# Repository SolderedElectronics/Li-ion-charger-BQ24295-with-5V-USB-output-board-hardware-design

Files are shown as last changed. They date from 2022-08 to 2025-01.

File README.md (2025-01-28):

# Li-ion charger BQ24295 with 5V USB output board Hardware Design

## About the Product

| Li-ion charger BQ24295 with 5V USB output board Image |
| :----------------------------------------------------------: |
| [Buy Li-ion charger BQ24295 with 5V USB output board](https://www.solde.red/333075) |

The BQ24295 is a versatile Li-ion battery charger designed to provide efficient and reliable charging for single-cell lithium-ion or lithium-polymer batteries. It supports various charging modes, including constant current (CC) and constant voltage (CV) charging, to ensure the battery is charged quickly and safely.

The BQ24295 charger operates on a wide input voltage range, typically from 4.35V to 17V, allowing it to be powered by a variety of power sources, including USB ports and AC adapters. It also features integrated power path management, which allows simultaneous charging of the battery while powering the connected device, providing uninterrupted operation.

---

## Repository Contents

This repository contains all design files for Li-ion charger BQ24295 with 5V USB output board, organized as follows:

- **`CAD` folder**: Contains KiCAD design files, including:
  - Schematics
  - PCB layout
  - Panel PCB layout
  - Source 3D files in Fusion360, if any
  - All files are sorted by version with a detailed change log.
- **`OUTPUTS` folder**: Includes all production-ready files, such as:
  - Bill of Materials (BOM) and interactive BOM (iBOM)
  - PDF versions of schematics
  - 3D `.step` file of the board
  - 3D-printable models
  - Gerber files for PCB manufacturing
  - Image of the pinout of the board
  - Product image
  - Compliance, legal and generic sales documents

Refer to the `Change Log` in the CAD folder for details about updates between versions.

---

## Learn More About the Product

Beyond the repository, explore the following resources:

### Soldered Verify

Soldered Verify Logo

The **Soldered Verify** system ensures every board you purchase from Soldered is fully functional. It also provides access to exclusive test data for your product. To get started, find the unique Soldered Verify ID on your product's packaging and enter the ID on the [Soldered Verify page](https://soldered.com/verify/) to access test results and additional product details.

### Soldered Community

soldered-verify-logo

Soldered Community is your go-to place for technical support. Our engineers track and answer all questions posted there, and it’s a great space for the maker community. Get answers to your questions and solutions for your challenges at [Soldered Community](https://soldered.com/community).

### solde.red

solde.red is an ultimate URL shortener and information hub. Access it by typing solde.red/ followed by your product SKU, e.g., [solde.red/333000](https://solde.red/333000), to find getting-started guides, datasheets, open-source hardware and software files, certifications, images, pinouts, and more. Read more about the shortener [here](https://solde.red/info/).

---

## Contributing

Contributions are welcome! Here’s how you can get involved:

- Submit pull requests to enhance the design or fix issues.
- Report bugs or problems by opening an issue.

We encourage community collaboration to make this product even better.

---

## About Soldered

soldered-logo

[Soldered for Makers](https://soldered.com) specializes in designing and manufacturing electronic products tailored for enthusiasts, ranging from hobbyists to professionals. Our portfolio includes electronic boards, sensors, and actuators that are widely utilized in fields such as microelectronics, mechatronics, robotics, programming, and IoT. Every product we offer is designed in-house and built upon open-source hardware and software platforms. Proudly certified and manufactured within the European Union, our catalog likely includes the product you need for your project.

We complement these products with comprehensive tutorials and manuals, product descriptions, schematics, programming codes, and project examples. Our round-the-clock [customer and technical support](https://soldered.com/community) is available for all our products, irrespective of the sales channel. Soldered’s success and services reflect our maker community’s unwavering [trust](https://www.trustpilot.com/review/soldered.com), for which we are deeply grateful. Join our community and create using Soldered products.

---

## License

All Soldered open-source hardware (OSH) is under The TAPR Open Hardware License. Read more in the LICENSE file located in this repository.

**Disclaimer:**

No warranty - all designs in this repository are distributed in the hope that they will be useful, but without any warranty. They are provided "AS IS", therefore without warranty of any kind, either expressed or implied. The entire quality and performance of what you do with the contents of this repository are your responsibility. In no event Soldered Electronics will be liable for your damages, or losses, including any general, special, incidental, or consequential damage arising out of the use or inability to use the contents of this repository. 

---

## Have fun!

Thank you for your support from your fellow makers at Soldered Electronics.

Happy Making!

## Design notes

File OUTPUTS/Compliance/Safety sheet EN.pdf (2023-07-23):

## Regulatory Compliance and Important Safety Information

PLEASE RETAIN THIS INFORMATION FOR FUTURE REFERENCE.

BEFORE USING THIS PRODUCT, READ ALL INSTRUCTION IN THIS DOCUMENT.

Product name: | Li-ion charger BQ24295 with 5V USB output board
Getting started: | To get started, please visit www.soldered.com

# WARNINGS

- This product should not be covered and should be operated in well ventilated enviroment.
- The product should be placed on a stable, flat, non-conductive surface and should not be contacted by conductive items.
- Connection of other devices may affect compliance or result in damage to the unit, and invalidate the warranty.
- Where peripherals are connected that do not include the cable or connector, the cable or connector used must offer adequate insulation and operation in order that the requirements of the relevant performance and safety requirements are met.
- There is a danger of explosion if the battery is incorrectly placed.
- The product should not be used outside of its specified working range.

# INSTRUCTIONS FOR SAFE USE

To avoid malfunction or damage to your device, please observe the following:
- Do not expose it to water, moisture or place on a conductive surface when turned on. Do not handle the unit with wet hands.
- Do not expose it to heat from any source; the product is designed to be used at normal ambient room temperatures. The product is intended to be used inside.
- Take care when handling to avoid mechanical or electrical damage to any part of the unit. Avoid handling the unit while it's powered. Use ESD protection.
- Use only supplied cable (or the cable of the same or higher quality) with the unit.

# COMPLIANCE INFORMATION

The product complies with the relevant provision of the RoHS Directive for the European Union. In common with all Electrical and Electronic Equipment (EEE), the product should not be disposed household waste.

ELECTROMAGNETIC COMPABILITY AND OPERATION

- The product is in conformity with the protection requirements of EU Council Directive 2014/30/EU on the laws of the Member States relating of electromagnetic compability, and Electromagnetic Compability Regulations 2016 of the UK.
- WARNING: Please do not alter the design of this product, doing so may void your ability to use the product freely, this includes altering the frequency at which product operates.

Soldered Electronics d.o.o., Reisnerova ulica 100, 31000 Osijek, Croatia. VAT ID: HR83200237288

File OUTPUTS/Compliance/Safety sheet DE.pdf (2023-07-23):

## Einhaltung gesetzlicher Vorschriften und wichtige Sicherheitsinformationen

BITTE BEWAHREN SIE DIESE INFORMATIONEN ZUR SPÄTEREN VERWENDUNG AUF.

LESEN SIE VOR DER VERWENDUNG DIESES PRODUKTS ALLE ANWEISUNGEN IN DOKUMENT.

Produktname: | Li-ion charger BQ24295 with 5V USB output board
Die ersten Schritte: | Besuchen Sie www.soldered.com, um loszulegen.

# WARNUNGEN

- Dieses Produkt sollte nicht abgedeckt werden und in einer gut belüfteten Umgebung betrieben werden.
- Das Produkt sollte auf einer stabilen, flachen, nicht leitenden Oberfläche aufgestellt werden und nicht mit leitenden Gegenständen in Berührung kommen.
- Der Anschluss anderer Geräte kann die Konformität beeinträchtigen oder zu Schäden am Gerät führen und zum Erlöschen der Garantie führen.
- Wenn Peripheriegeräte angeschlossen werden, die nicht das Kabel oder den Stecker enthalten, muss das verwendete Kabel oder muss das verwendete Kabel bzw. der verwendete Steckverbinder eine angemessene Isolierung und Funktion aufweisen, damit die Anforderungen die einschlägigen Leistungs- und Sicherheitsanforderungen erfüllt werden.
- Es besteht Explosionsgefahr, wenn die Batterie falsch eingesetzt wird.
- Das Produkt sollte nicht außerhalb des angegebenen Arbeitsbereichs verwendet werden.

# HINWEISE ZUR SICHEREN ANWENDUNG

Um Fehlfunktionen oder Schäden an Ihrem Gerät zu vermeiden, beachten Sie bitte die folgenden Hinweise:
- Setzen Sie das Gerät nicht Wasser oder Feuchtigkeit aus und stellen Sie es nicht auf eine
leitende Oberfläche, wenn es eingeschaltet ist. Das Gerät nicht mit nassen Händen anfassen.
- Setzen Sie es keiner Wärmequelle aus; das Produkt ist für die Verwendung bei normalen Raumtemperaturen ausgelegt. Das Produkt ist für die Verwendung in Innenräumen vorgesehen.
- Seien Sie bei der Handhabung vorsichtig, um mechanische oder elektrische Schäden an Teilen des Geräts zu vermeiden. Fassen Sie das Gerät nicht an, wenn es unter Spannung steht. Verwenden Sie einen ESD-Schutz.
- Verwenden Sie nur das mitgelieferte Kabel (oder ein gleich- oder höherwertiges Kabel)
mit dem Gerät.

# COMPLIANCE-INFORMATIONEN

Das Produkt entspricht den entsprechenden Bestimmungen der RoHS-Richtlinie für die Europäische Union. Wie alle elektrischen und elektronischen Geräte (EEE), sollte das Produkt nicht über den Hausmüll entsorgt werden.
ELEKTROMAGNETISCHE VERTRÄGLICHKEIT UND BETRIEB
- Das Produkt entspricht den Schutzanforderungen der Richtlinie des EU-Rates 2014/30/EU über die Rechtsvorschriften der Mitgliedstaaten zur elektromagnetischen Verträglichkeit und den Elektromagnetische Verträglichkeitsverordnung 2016 des Vereinigten Königreichs.
- WARNUNG: Bitte verändern Sie nicht das Design dieses Produkts, da dies dazu führen kann, dass Sie das Produkt nicht mehr uneingeschränkt nutzen können.
Dies gilt auch für die Änderung der Frequenz, mit der das Produkt arbeitet.

Soldered Electronics d.o.o., Reisnerova ulica 100, 31000 Osijek, Croatia. VAT ID: HR83200237288

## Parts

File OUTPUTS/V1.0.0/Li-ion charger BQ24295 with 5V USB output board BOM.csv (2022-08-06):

Id | Designator | Package | Quantity | Designation | Supplier and ref
1 | G*** | Symbol-Front-USB | 1 | LOGO
2 | U1 | SOT-363 | 1 | NMOS-DUAL
3 | C4 | 0603C | 1 | CL10B473KO8NNNC
4 | G*** | Logo-Back-OSH-3.5mm | 1 | LOGO
5 | R12,R14,R1 | 0603R | 3 | 5.1k
6 | R3,R6,R10,R9,R8,R5,R2,R7 | 0603R | 8 | 10k
7 | K12 | USB_A_FEMALE_CONECTOR | 1 | USB_A_FEMALE_CONNECTOR
8 | D2 | 0402LED | 1 | purple
9 | ,,,,,,,,,,,,,,,,,,,,,,,,, | buzzardLabel | 26
10 | K6 | HEADER_MALE_4X1 | 1 | HEADER_MALE_4X1
11 | K4 | U262-161N-4BVC11 | 1 | U262-161N-4BVC11
12 | R15 | 0603R | 1 | 1k
13 | JP3,JP1 | SMD_JUMPER_3_PAD_TRACE | 2 | SMD_JUMPER_3_PAD_TRACE
14 | U2 | BQ24295RGET | 1 | BQ24295_RGET
15 | JP6,JP2 | SMD-JUMPER-CONNECTED_TRACE_SLODERMASK | 2 | SMD-JUMPER-CONNECTED_TRACE_SLODERMASK
16 | D1 | 0402LED | 1 | red
17 | G***,G*** | Logo-Front-easyC-5mm | 2 | LOGO
18 | FD1 | FIDUCIAL_23 | 1 | FIDUCIAL
19 | JP5 | SMD_JUMPER | 1 | SMD_JUMPER
20 | C2 | 1206C | 1 | EMK316BB7226ML-T
21 | K1,K10 | HEADER_MALE_2X1 | 2 | HEADER_MALE_2X1
22 | K2,K3,K8,K9 | HEADER_MALE_1X1 | 4 | HEADER_MALE_1X1
23 | H1,H2,H4,H3 | HOLE_3.2mm | 4 | HOLE_3.2mm
24 | R11,R16 | 0402R | 2 | 2k2
25 | K7 | JST-2pin-SMD | 1 | JST-2pin-SMD
26 | K5,K11 | easyC-connector | 2 | easyC-SMD
27 | C7,C5,C6 | 1206C | 3 | CL31B106MOHNNNE
28 | L1 | SRN5020TA-2R2M | 1 | SRN5020TA__2R2M
29 | U3 | SOT-23-5 | 1 | SE5218
30 | REF** | Logo-Back-SolderedFULL-20mm | 1 | Logo-Front-SolderedFULL-20mm
31 | R13 | 0603R | 1 | 150R
32 | G*** | Symbol-Front-Battery | 1 | LOGO
33 | C3 | 0805C | 1 | GRM21BR71C475KE51K
34 | G*** | Logo-Front-Soldered-6mm | 1 | LOGO
35 | R4 | 0603R | 1 | 33k
36 | C8,C9 | 0603C | 2 | 2.2uF
37 | C1 | 0603C | 1 | CL10B105KO8NNNL
38 | JP4 | SMD_JUMPER_CONNECTED | 1 | SMD-JUMPER-CONNECTED
39 | Ref** | Version1.0.0. | 1 | Val**
40 | REF** | Symbol-Front-I2C-ADDR-Field | 1 | Symbol-Front-I2C-ADDR-Field

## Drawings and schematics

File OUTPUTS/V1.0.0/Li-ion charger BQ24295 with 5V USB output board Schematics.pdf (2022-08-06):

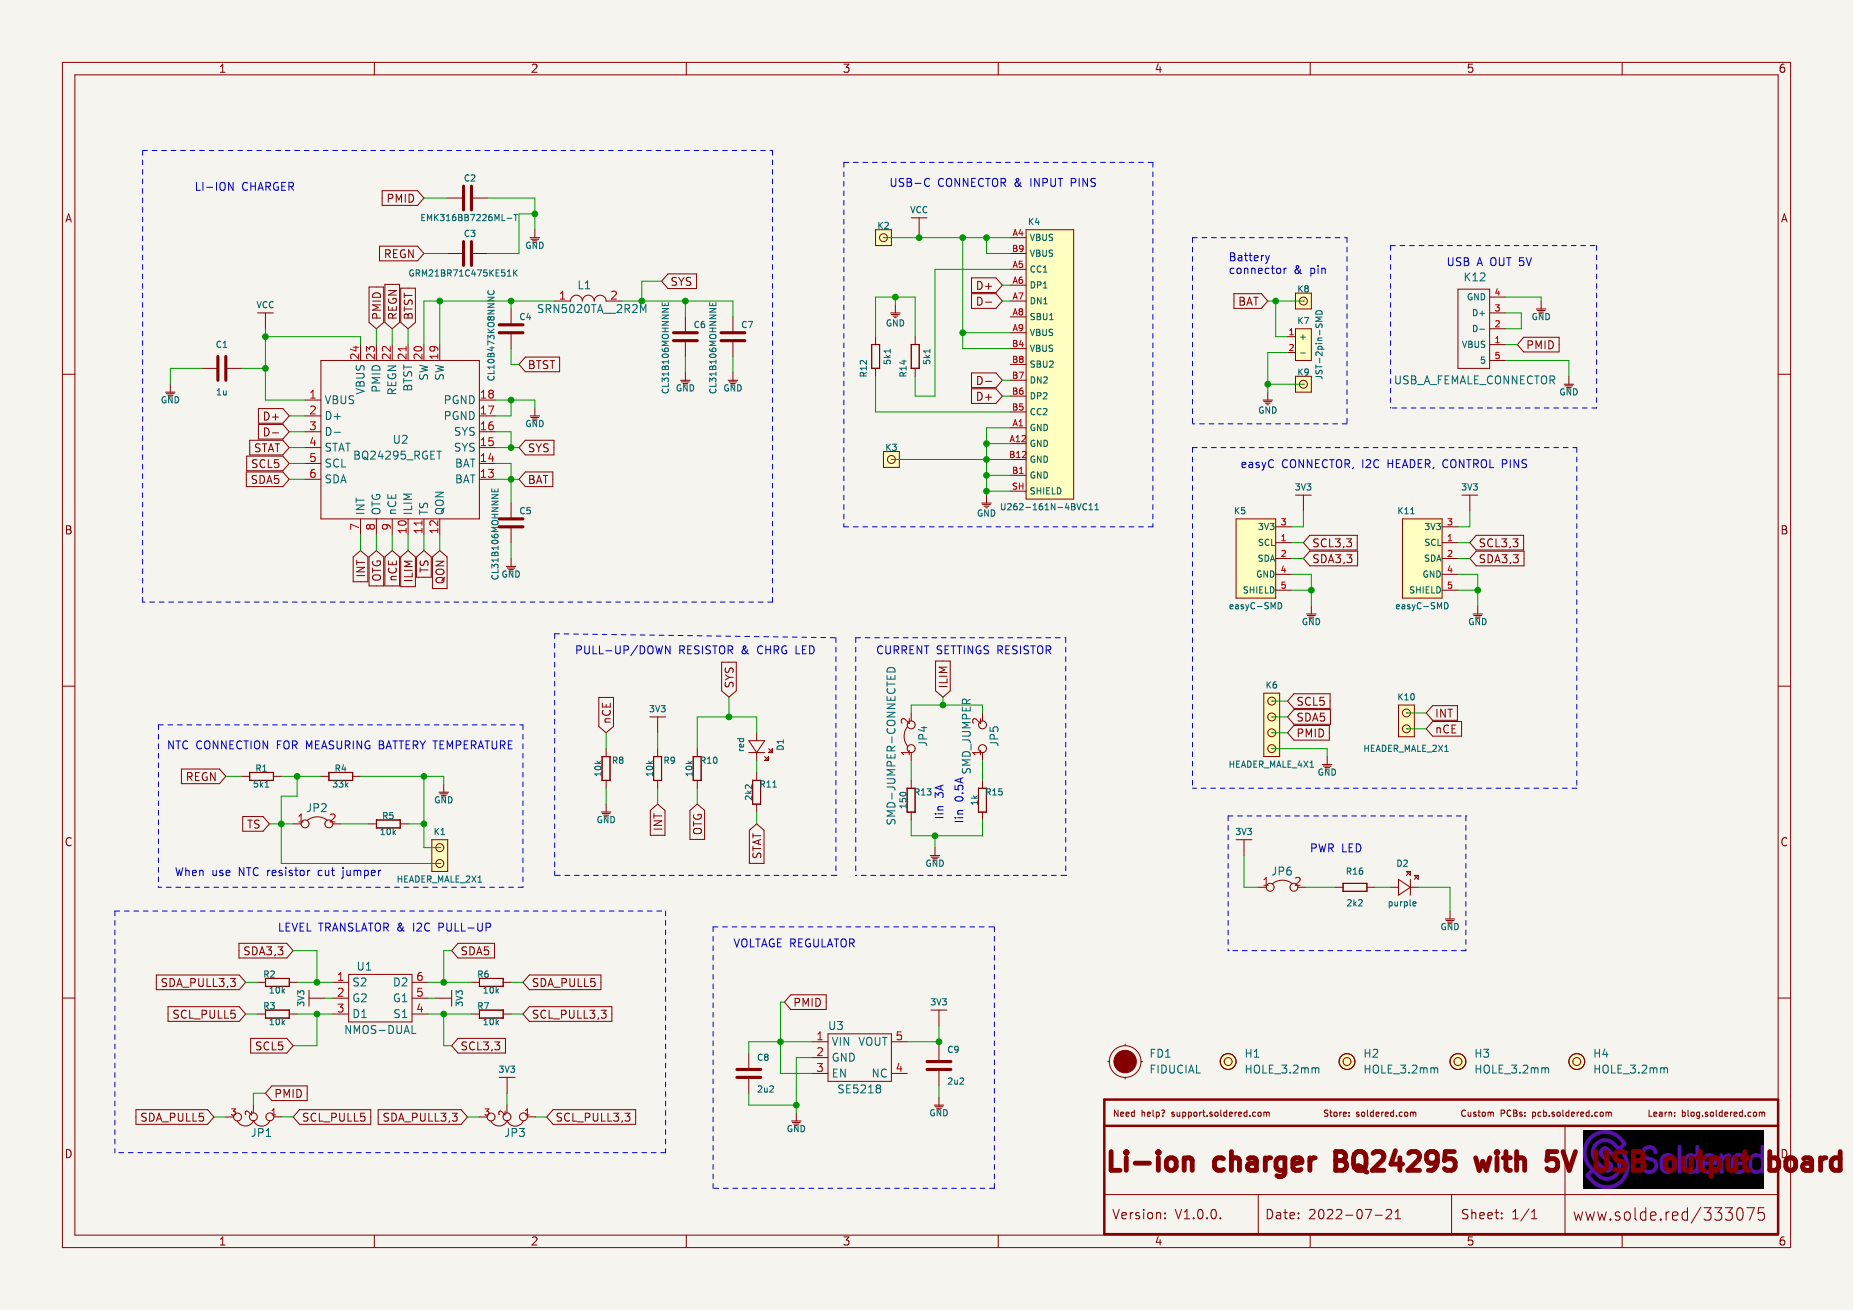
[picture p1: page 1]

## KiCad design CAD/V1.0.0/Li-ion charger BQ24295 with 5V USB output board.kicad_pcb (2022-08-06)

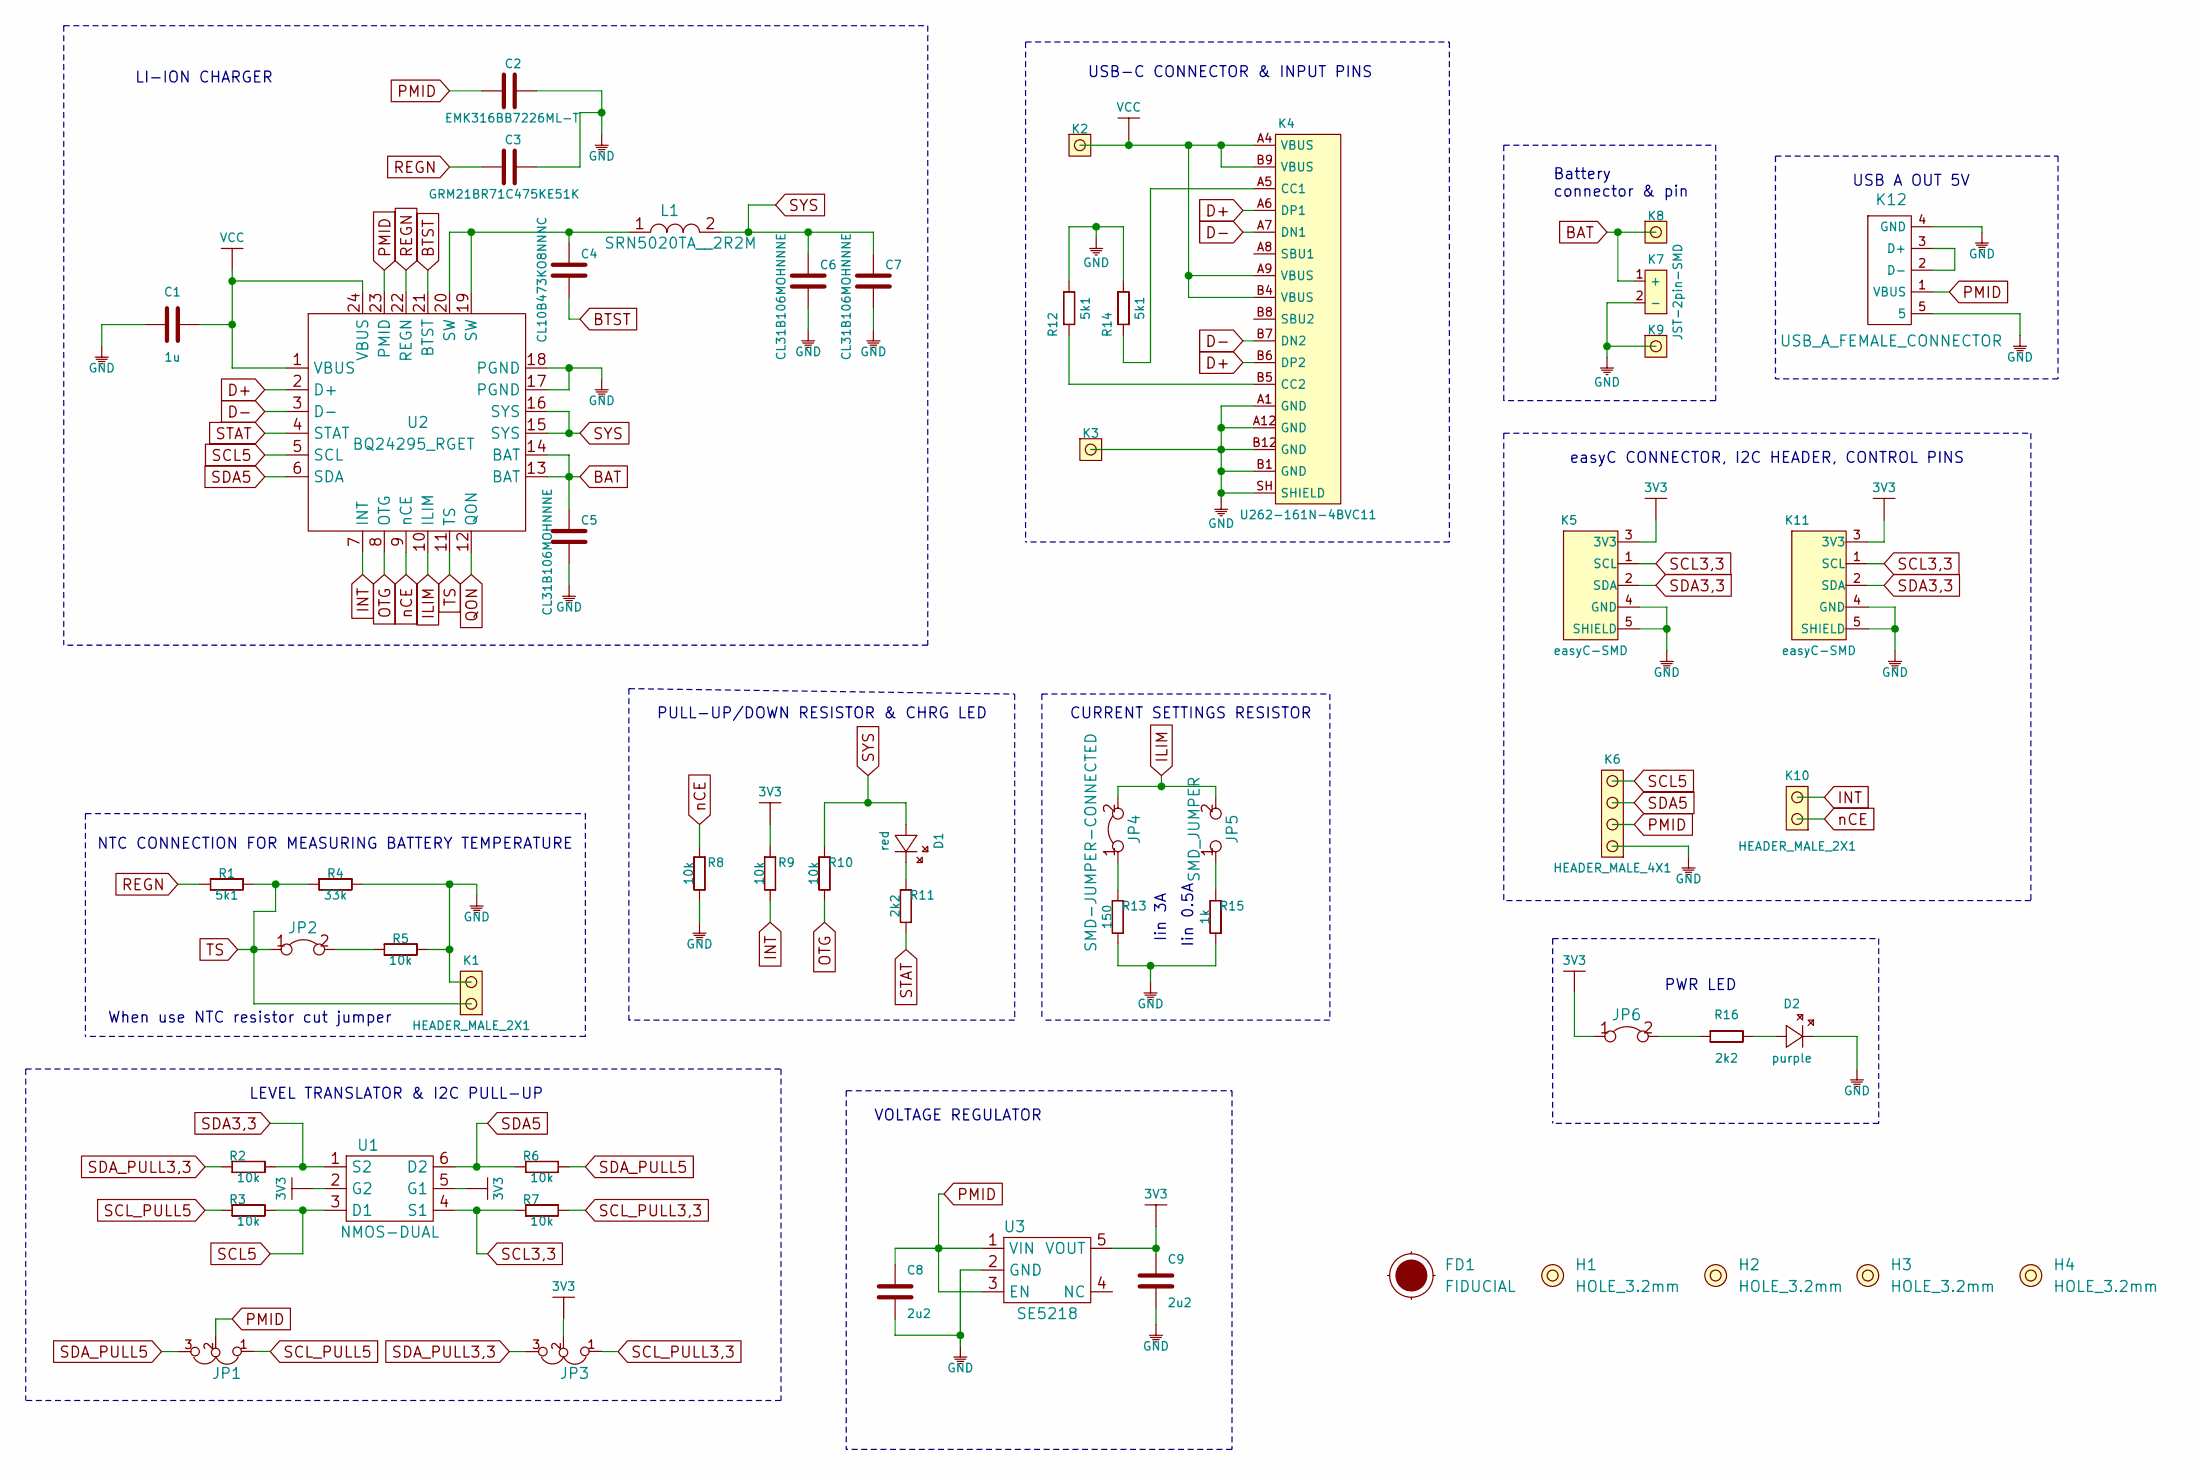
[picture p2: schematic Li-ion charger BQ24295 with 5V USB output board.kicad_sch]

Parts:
C1: 1u; 0603C
C2: EMK316BB7226ML-T; 1206C
C3: GRM21BR71C475KE51K; 0805C
C4: CL10B473KO8NNNC; 0603C
C5, C6, C7: CL31B106MOHNNNE; 1206C
C8, C9: 2u2; 0603C
D1: red; 0402LED
D2: purple; 0402LED
FD1: FIDUCIAL; FIDUCIAL_23
H1, H2, H3, H4: HOLE_3.2mm
JP1, JP3: SMD_JUMPER_3_PAD_TRACE
JP2, JP6: SMD-JUMPER-CONNECTED_TRACE_SLODERMASK
JP4: SMD-JUMPER-CONNECTED; SMD_JUMPER_CONNECTED
JP5: SMD_JUMPER
K1, K10: HEADER_MALE_2X1
K2, K3, K8, K9: HEADER_MALE_1X1
K4: U262-161N-4BVC11
K5, K11: easyC-SMD; easyC-connector
K6: HEADER_MALE_4X1
K7: JST-2pin-SMD
K12: USB_A_FEMALE_CONNECTOR; USB_A_FEMALE_CONECTOR
L1: SRN5020TA__2R2M; SRN5020TA-2R2M
R1, R12, R14: 5k1; 0603R
R2, R3, R5, R6, R7, R8, R9, R10: 10k; 0603R
R4: 33k; 0603R
R11, R16: 2k2; 0402R
R13: 150; 0603R
R15: 1k; 0603R
U1: NMOS-DUAL; SOT-363
U2: BQ24295_RGET; BQ24295RGET
U3: SE5218; SOT-23-5

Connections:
3V3: C9.2, JP3.2, JP6.1, K5.3 (3V3), K11.3 (3V3), R9.1, U1.2 (G2), U1.5 (G1), U3.5 (VOUT)
BAT: C5.2, K7.1 (+), K8.1, U2.13 (BAT), U2.14 (BAT)
BTST: C4.1, U2.21 (BTST)
D+: K4.A6 (DP1), K4.B6 (DP2), U2.2 (D+)
D-: K4.A7 (DN1), K4.B7 (DN2), U2.3 (D-)
GND: C1.1, C2.1, C3.1, C5.1, C6.1, C7.1, C8.1, C9.1, D2.2 (K), K1.2, K3.1, K4.A1 (GND), K4.A12 (GND), K4.B1 (GND), K4.B12 (GND), K4.SH (SHIELD), K5.4 (GND), K5.5 (SHIELD), K6.1, K7.2 (-), K9.1, K11.4 (GND), K11.5 (SHIELD), K12.4 (GND), K12.5, R4.2, R5.2, R8.2, R12.2, R13.2, R14.2, R15.2, U2.17 (PGND), U2.18 (PGND), U3.2 (GND)
ILIM: JP4.2, JP5.2, U2.10 (ILIM)
INT: K10.2, R9.2, U2.7 (INT)
unnamed: C4.2, L1.1, U2.19 (SW), U2.20 (SW)
unnamed: D1.2 (K), R11.1
unnamed: D2.1 (A), R16.2
unnamed: JP2.2, R5.1
unnamed: JP4.1, R13.1
unnamed: JP5.1, R15.1
unnamed: JP6.2, R16.1
unnamed: K4.A5 (CC1), R14.1
unnamed: K4.B5 (CC2), R12.1
unnamed: K12.2 (D-), K12.3 (D+)
OTG: R10.2, U2.8 (OTG)
PMID: C2.2, C8.2, JP1.2, K6.2, K12.1 (VBUS), U2.23 (PMID), U3.1 (VIN), U3.3 (EN)
QON: U2.12 (QON)
REGN: C3.2, R1.1, U2.22 (REGN)
SCL3,3: K5.1 (SCL), K11.1 (SCL), R7.1, U1.4 (S1)
SCL5: K6.4, R3.2, U1.3 (D1), U2.5 (SCL)
SCL_PULL3,3: JP3.1, R7.2
SCL_PULL5: JP1.1, R3.1
SDA3,3: K5.2 (SDA), K11.2 (SDA), R2.2, U1.1 (S2)
SDA5: K6.3, R6.1, U1.6 (D2), U2.6 (SDA)
SDA_PULL3,3: JP3.3, R2.1
SDA_PULL5: JP1.3, R6.2
STAT: R11.2, U2.4 (STAT)
SYS: C6.2, C7.2, D1.1 (A), L1.2, R10.1, U2.15 (SYS), U2.16 (SYS)
TS: JP2.1, K1.1, R1.2, R4.1, U2.11 (TS)
VCC: C1.2, K2.1, K4.A4 (VBUS), K4.A9 (VBUS), K4.B4 (VBUS), K4.B9 (VBUS), U2.1 (VBUS), U2.24 (VBUS)
nCE: K10.1, R8.1, U2.9 (nCE)

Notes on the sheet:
LEVEL TRANSLATOR & I2C PULL-UP
CURRENT SETTINGS RESISTOR
When use NTC resistor cut jumper
easyC CONNECTOR, I2C HEADER, CONTROL PINS
PULL-UP/DOWN RESISTOR & CHRG LED
NTC CONNECTION FOR MEASURING BATTERY TEMPERATURE
Battery connector & pin
USB A OUT 5V
VOLTAGE REGULATOR
PWR LED
Iin 3A
USB-C CONNECTOR & INPUT PINS
Iin 0.5A
LI-ION CHARGER

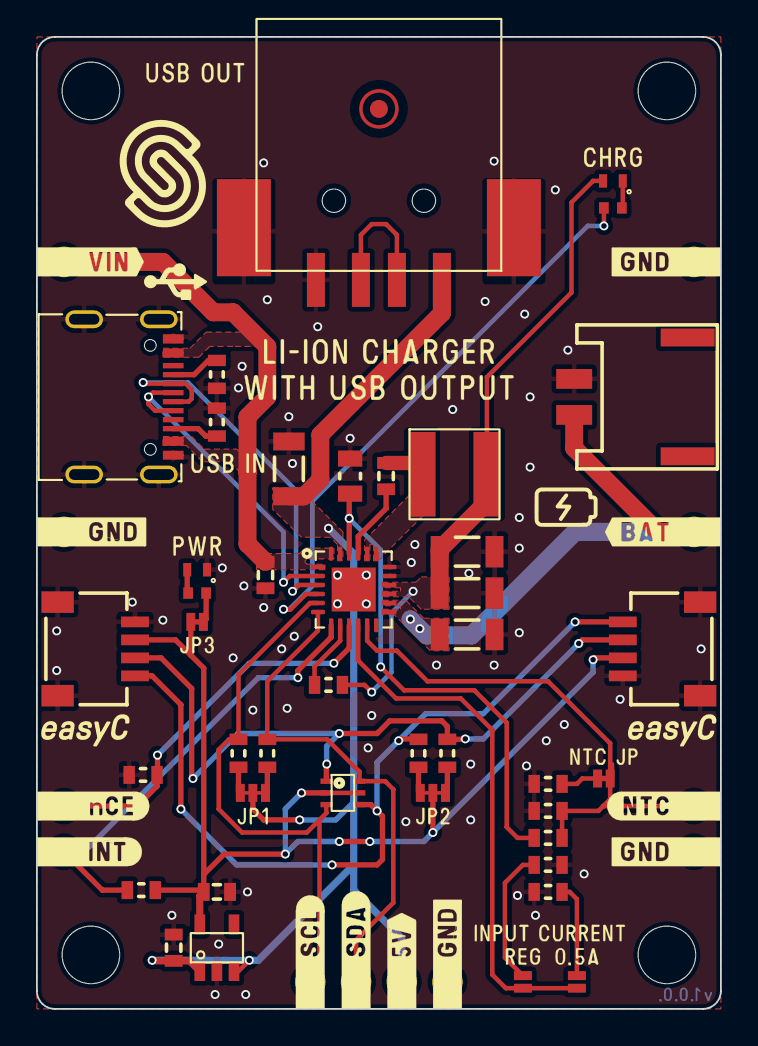
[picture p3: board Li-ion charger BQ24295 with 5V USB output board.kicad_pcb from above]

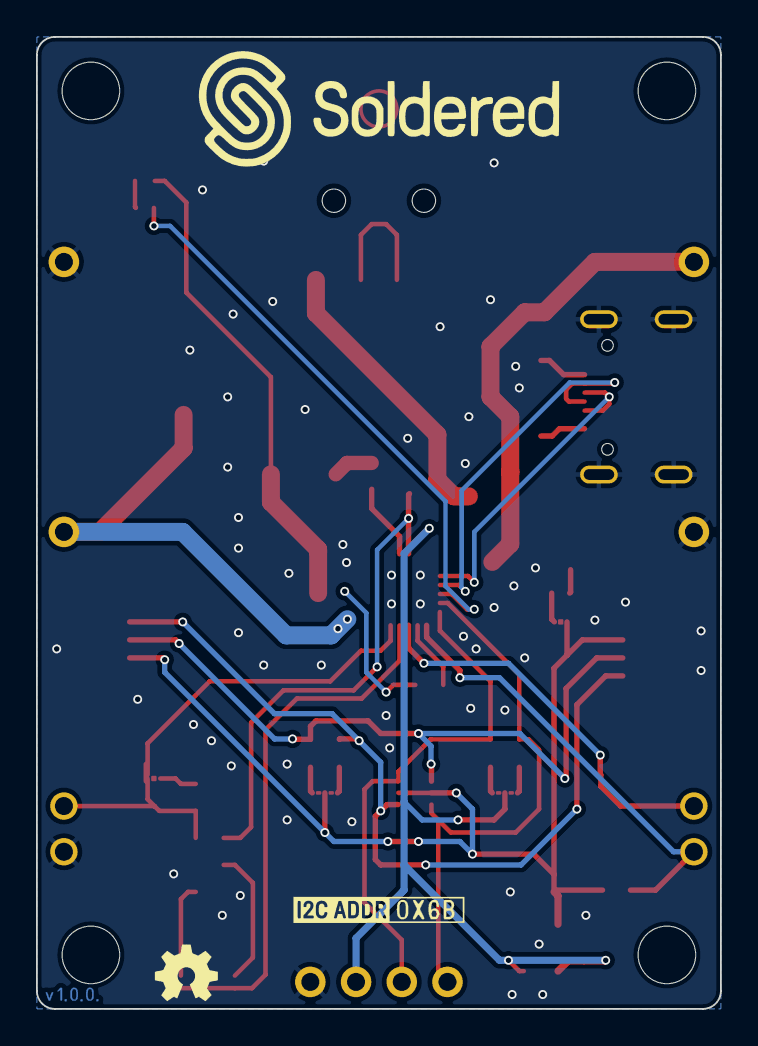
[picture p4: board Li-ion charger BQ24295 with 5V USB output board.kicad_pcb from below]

Board: 2 copper layers, 38.0 x 54.0 mm, 55 parts (8 on the bottom side), 34 nets.

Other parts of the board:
Ref**: Val**; Version1.0.0.

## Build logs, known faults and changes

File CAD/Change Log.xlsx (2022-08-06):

CHANGE LOG
 | Latest version |  |  | v1.0.0.
 |  | Product name: |  | Li-ion charger BQ24295 with 5V USB output board
 |  | Release date: |  | 21.7.2021.
 |  | Release author: |  | Ivan Fadiga
Version: | v1.0.0. | Author: | Ivan Fadiga | Date: | 21.7.2021.
List of Changes
 | Initial document
Version: |  | Author: |  | Date:
List of Changes
Version: |  | Author: |  | Date:
List of Changes

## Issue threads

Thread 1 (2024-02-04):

Neispravna poveznica na sliku u README.md ?

sbravar, 2024-02-04:
https://github.com/SolderedElectronics/Li-ion-charger-BQ24295-with-5V-USB-output-board-hardware-design/blob/7294943773bb3a7f665f644393ce3a54e7380dfc/README.md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

umjesto:

https://github.com/SolderedElectronics/Li-ion-charger-BQ24295-with-5V-USB-output-board-hardware-design/blob/main/OUTPUTS/V1.1.1/333075.jpg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

čini mi se da bi trebalo biti:

https://github.com/SolderedElectronics/Li-ion-charger-BQ24295-with-5V-USB-output-board-hardware-design/blob/main/OUTPUTS/V1.0.0/333075.jpg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

Closed 2024-02-05.
